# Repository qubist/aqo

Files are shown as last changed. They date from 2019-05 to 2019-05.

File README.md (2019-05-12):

# aqo

Banner image of aqo next to a monitor and keyboard



> Air Quality Object which beautifully and passively displays the level of CO2 in the air

## Table of Contents

- [Background](#background)
- [Install/Assembly](#installassembly)
- [Parts](#parts)
- [Usage](#usage)
- [Maintainers](#maintainers)
- [Contributing](#contributing)
- [License](#license)

## Background

[Too much CO2 in the air affects how well brains function.](https://ehp.niehs.nih.gov/doi/pdf/10.1289/ehp.1510037#page=6&zoom=auto,-131,530) The Air Quality Object changes color depending on air CO2 content. It's meant to be a beautiful object which also passively displays information about the surroundings. It makes a normally invisible flow visible, so you can open a window when your air is getting stale.

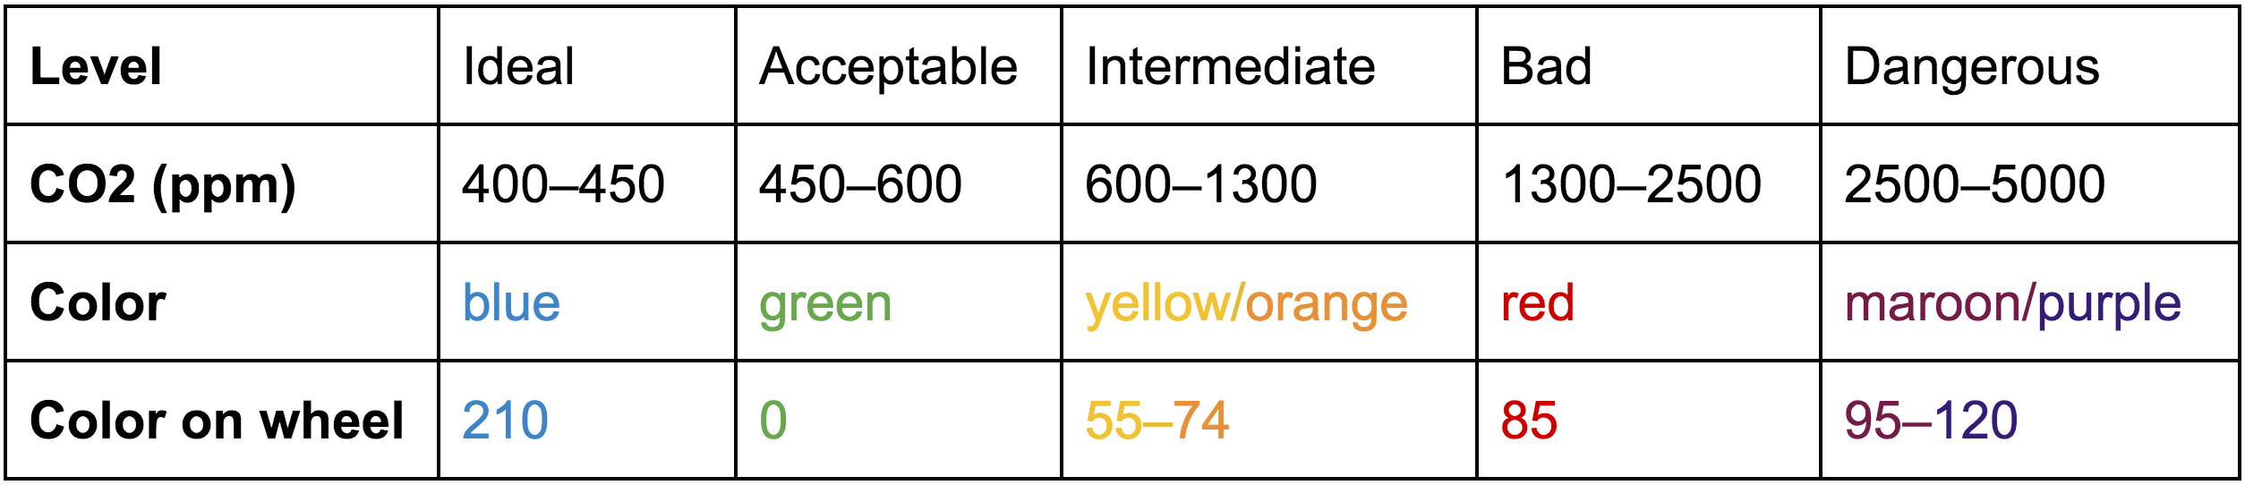
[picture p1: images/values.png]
Chart displaying 5 levels of air quality. Each level has three data points: CO2 (ppm), Color, and Color on wheel. Ideal: 400–450 ppm, blue, 210; Acceptable: 450–600 ppm, green, 0; Intermediate: 600–1300 ppm, yellow/orange, 55–74; Bad: 1300–2500, red, 85; Dangerous: 2500–5000, maroon/purple, 95–120


aqo alongside parts required to build it

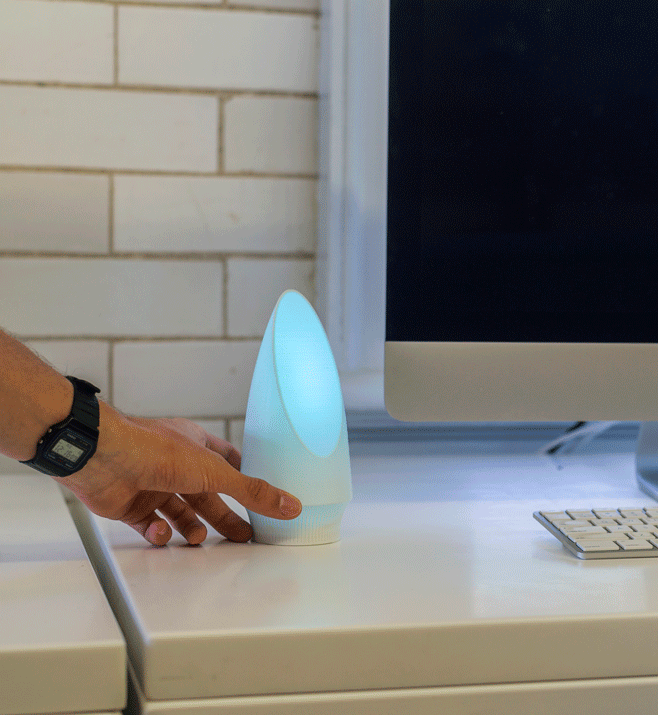
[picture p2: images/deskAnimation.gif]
Gif showing an aqo displaying various colors being touched by a hand wearing a watch


## Install/Assembly

Install the code on an [Adafruit Feather M0 Express](https://www.adafruit.com/product/3403) by dragging the contents of the [code](/code) folder (`lib`, `main.py` and `helpers.py`) onto the Feather's CIRCUITPY drive.

aqo next to a laptop showing code

### Parts
* [Adafruit SGP30 Air Quality Sensor Breakout](https://www.adafruit.com/product/3709) for measuring CO2
* [Adafruit NeoPixel Stick 8x RGB LED](https://www.adafruit.com/product/1426) for displaying the color
* [3.7v 1200mAh LiPo Battery](https://www.adafruit.com/product/258) for backup power
* [Adafruit Feather M0 Express](https://www.adafruit.com/product/3403) to control everything

Parts that are used to create aqo

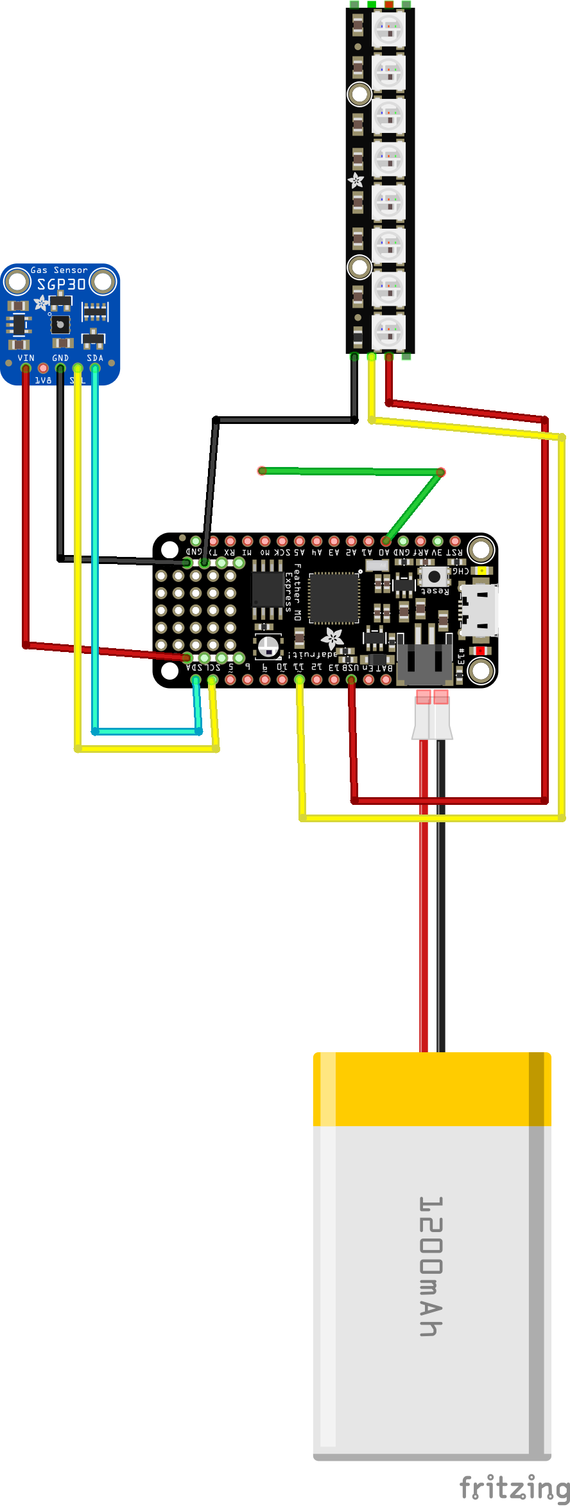
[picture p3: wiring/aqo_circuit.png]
Circuit diagram for the aqo, showing how to connect the Feather M0, SPG30, NeoPixel Bar, and battery together


## Usage

The aqo will start displaying the color based on what CO2 readings it's getting. At first, this won't be accurate. Bring it outside for like 10 minutes so that the sensor can get a baseline reading of clean air. Then after a while it should display the colors accurately to the CO2 levels in the air.*

Touch the touchwire on the back of the aqo to change which brightness mode you're in. The brightest one is good for daytime, middle is good for nighttime, and lowest is good for sleeping.

The aqo should stay plugged in, but it has a battery and can be unplugged for periods of time. This is useful so you can transport it or take it outside without it rebooting and losing its calibration.

To remove the bottom cover for maintenance, twist it and the magnets will disengage. Then it should pop free. You can also lever it free using the power cable or maybe even shake it free.

\* I'm not 100% sure about all this stuff. I'll try and figure it out later.

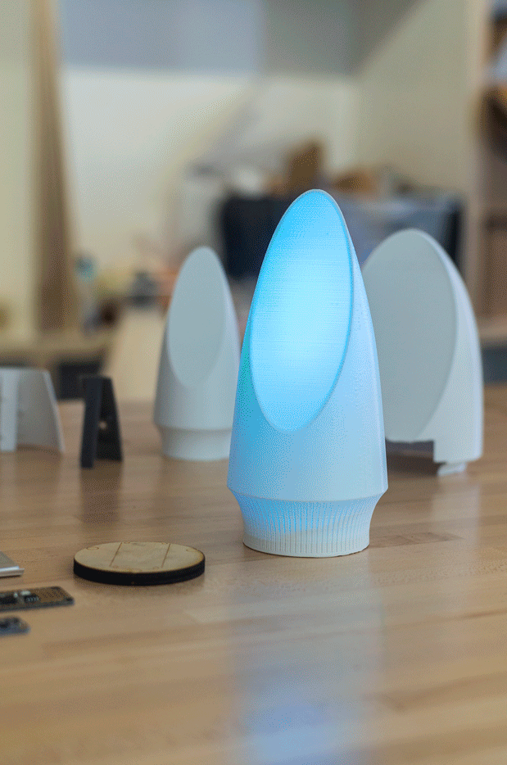
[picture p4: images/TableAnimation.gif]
Gif showing an aqo displaying various colors sitting on a table


## Maintainers

[@qubist](https://github.com/qubist)

## Contributing

PRs accepted.

Note: If editing the README, please conform to the [standard-readme](https://github.com/RichardLitt/standard-readme) specification.

## License

MIT © 2019 Will

Banner image of aqo showing orange next to a Prusa i3 Mk2 3D printer

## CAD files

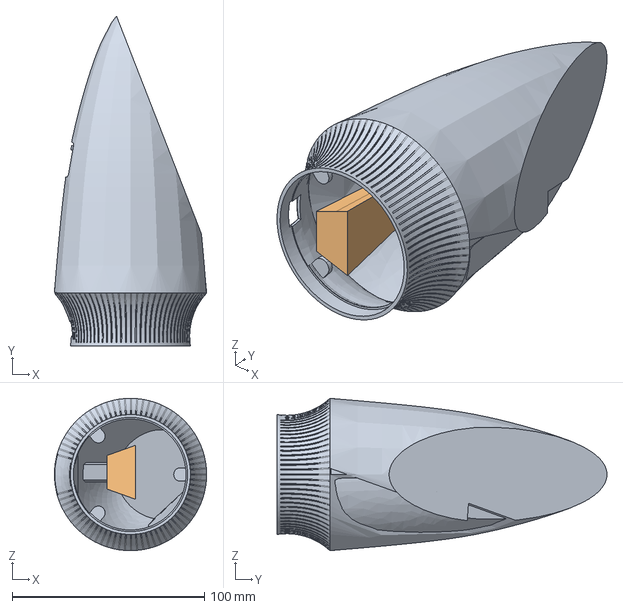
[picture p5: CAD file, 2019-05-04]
case/Case.igs
79.2 x 171.7 x 79.2 mm

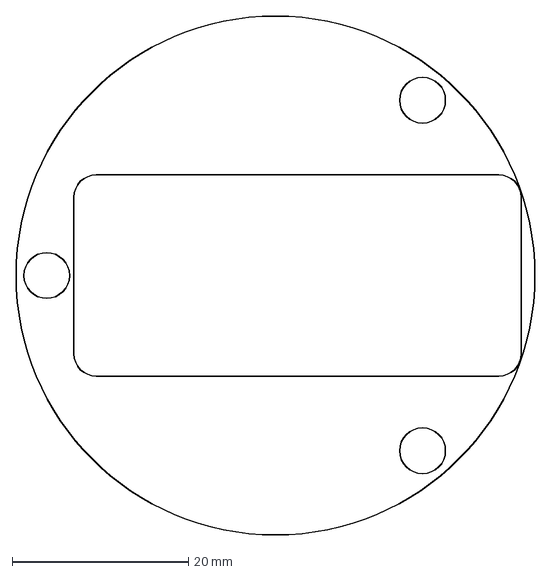
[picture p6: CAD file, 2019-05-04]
case/aqo_bottom_cover_v124.dxf
58.9 x 58.9 mm

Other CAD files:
case/Case.f3z

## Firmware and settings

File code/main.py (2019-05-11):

import time
import board
import busio
import adafruit_sgp30
import neopixel
import touchio
from analogio import AnalogIn

from helpers import *

PIXEL_PIN = board.D11
NUM_PIXELS = 8

# pin with touch sensitivity
TOUCH_PIN = board.A0

# pin with battery voltage for checking battery level
VBATPIN = board.D9

DISPLAY_BRIGHTNESS = 1

# number of entries to average to get the displayed value
# the higher this is, the slower and smoother color transitions will be
# 60-80 seems to be good for nice slow transitions while staying responsive
BLUR_AMOUNT = 25

# LOWBAT_PULSE_SPEED = 200
# LOWBAT_PULSE_DEPTH = 200

# voltages at which low battery mode is turned off or on when battery voltage is
# ascending or descending
# VBAT_DESCENT_THRESHOLD = 3.35
# VBAT_ASCENT_THRESHOLD = 3.45

# in each mode, how much to dim the pixels and how many of the pixels to light
DEFAULT_DIM_FACTOR = 1 # don't dim in mode 0
DEFAULT_DIM_MAPPING = [1,1,1,1,1,1,1,1]

FIRST_DIM_FACTOR  = 1 # don't dim
FIRST_DIM_MAPPING = [0,1,0,0,1,0,0,1]

SECOND_DIM_FACTOR = 20 # dim a lot mode 2
SECOND_DIM_MAPPING = [1,0,0,0,0,0,0,0]

UBER_DIM_FACTOR = 30

# set up pixel array
pixels = neopixel.NeoPixel(PIXEL_PIN, NUM_PIXELS, brightness=DISPLAY_BRIGHTNESS, auto_write=True)

# set up touch sensitivity
touch_pad = TOUCH_PIN
touch = touchio.TouchIn(touch_pad)

# VBatAnalogIn = AnalogIn(VBATPIN)
# def getBatteryVoltage():
#     return getVoltage(VBatAnalogIn) * 2

# Turn off board neopixel
boardPixel = neopixel.NeoPixel(board.NEOPIXEL, 1, auto_write=True)
boardPixel[0] = 0

# Set up I2C for CO2 sensor
i2c = busio.I2C(board.SCL, board.SDA, frequency=100000)
# Create library object on our I2C port
sgp30 = adafruit_sgp30.Adafruit_SGP30(i2c)
print("SGP30 serial #", [hex(i) for i in sgp30.serial])
sgp30.iaq_init()
sgp30.set_iaq_baseline(0x8973, 0x8aae)

# define an average function that calculates the average of our values
def avg(lst):
    return sum(lst)/BLUR_AMOUNT

# returns a value on the color wheel described in the wheel() function
# based a given CO2 level
def getWheelValueFromCO2(CO2):
    if inRange(CO2, 400,450):
        return mapFromTo(CO2, 400,450, 210,255)
    elif inRange(CO2, 450,600):
        return mapFromTo(CO2, 450,600, 0,55)
    elif inRange(CO2, 600,1300):
        return mapFromTo(CO2, 600,1300, 55,85)
    elif inRange(CO2, 1300,2500):
        return mapFromTo(CO2, 1300,2500, 85,95)
    elif inRange(CO2, 2500,5000):
        return mapFromTo(CO2, 2500,5000, 95,120)
    else:
        return 120

# returns a color
def getColorFromCO2(CO2):
    return wheel(getWheelValueFromCO2(CO2))

# shows the color, lighting the pixels corresponding to 1s in a binary array
def showColor(color, mapping=[1,1,1,1,1,1,1,1]):
    # if in UberDIM mode, turn off all pixels but light the board pixel
    if(mapping == "uberdim"):
        pixels.fill(0)
        boardPixel[0] = color
    else:
        # turn off the board pixel
        boardPixel[0] = 0
        # crawl the mapping and light up the pixels which should be activated
        for n,m in enumerate(mapping):
            if m == 1:
                pixels[n] = color
            else:
                pixels[n] = 0

# runs a startup animation
# lights turn on from bottom to top, with a slight color change.
def startupAnimation(delay, destinationColor, colorStep):
    # start out with all pixels off
    animationMapping = [0,0,0,0,0,0,0,0]
    i = 0
    # start the color the right amount away from destination
    color = destinationColor + colorStep * 8
    for i in range(8):
        animationMapping[i] = 1
        showColor(wheel(color), animationMapping)
        color -= colorStep
        time.sleep(delay)

# set up list of last values to update and average
vals = [400 for x in range(BLUR_AMOUNT)]
# batLow = False
tick = int(time.monotonic())

touched = False
mode = 0

# show startup animation
startupAnimation(.045, 210, 3)

while True:
    # update which second are we on, and save the last one
    lastTick = [tick][0]
    tick = int(time.monotonic())

    # check touches and cycle through brightness modes if new touch is detected
    if touch.value:
        if touched == False:
            # activate touch functions
            # print("TOUCHED!")
            # increment mode
            mode = increment(mode)

            touched = True
    else:
        touched = False

    # grab the carbon dioxide and TVOC levels from the sensor
    # eCO2, TVOC = sgp30.eCO2, sgp30.TVOC
    eCO2 = sgp30.eCO2

    # only do the following every 10 seconds (on rising edge of 10th second)
    # if tick % 10 == 0 and lastTick %10 != 0:
    #     # get the battery voltage
    #     voltage = getBatteryVoltage()
    #     print(voltage)
    #     if batLow == False and voltage <= VBAT_DESCENT_THRESHOLD:
    #         batLow = True
    #     elif batLow == True and voltage >= VBAT_ASCENT_THRESHOLD:
    #         batLow = False

    # remove oldest datapoint from our list of values and add the new datapoint
    vals.remove(vals[0])
    vals.append(eCO2)

    # the value we'll work with is the average of our list of values
    blurredVal = avg(vals)

    # these print statements are usefull, but slow down the program if it's not
    # plugged in and able to actually print to serial
    # print(vals)
    # print("eCO2 = %d ppm" % (sgp30.eCO2))
    # print(blurredVal)
    # print(voltage)

    c = getColorFromCO2(blurredVal)
    if mode == 0:
        displayColor = c # don't dim
        pixelMapping = DEFAULT_DIM_MAPPING
    elif mode == 1:
        displayColor = dim(c, FIRST_DIM_FACTOR)
        pixelMapping = FIRST_DIM_MAPPING
    elif mode == 2:
        displayColor = dim(c, SECOND_DIM_FACTOR) # SuperDim for nighttime :)
        pixelMapping = SECOND_DIM_MAPPING
    elif mode == 3:
        displayColor = dim(c, UBER_DIM_FACTOR) # UberDIM !! >:}
        pixelMapping = "uberdim"

    # # pulse the display color if in low battery mode
    # if batLow == True:
    #     ShowColor(pulse(displayColor, LOWBAT_PULSE_SPEED, LOWBAT_PULSE_DEPTH), pixelMapping)
    # # otherwise just display the color
    # else:
    showColor(displayColor, pixelMapping)

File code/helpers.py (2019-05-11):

import time

MAX_MODE = 3

def wheel(pos):
    # Input a value 0 to 255 to get a color value.
    # The colours are a transition r - g - b - back to r.
    if pos < 0 or pos > 255:
        r = g = b = 0
    elif pos < 85:
        r = int(pos * 3)
        g = int(255 - pos*3)
        b = 0
    elif pos < 170:
        pos -= 85
        r = int(255 - pos*3)
        g = 0
        b = int(pos*3)
    else:
        pos -= 170
        r = 0
        g = int(pos*3)
        b = int(255 - pos*3)
    return (r, g, b)

# x    input value;
# a,b  input range
# c,d  output range
# y    return value
def mapFromTo(x,a,b,c,d):
   y=(x-a)/(b-a)*(d-c)+c
   return y

# returns bool: whether n is in the given range
# lower inclusive, upper exclusive (min <= n < max)
def inRange(n, min, max):
    return n < max and n >= min

def dim(color, factor):
    r, g, b = color
    dimmedColor = int(r/factor), int(g/factor), int(b/factor)
    return dimmedColor

def getVoltage(pin):
    return (pin.value * 3.3) / 65536

# pulses the input color's brightness according to the device time
# speed: the speed at which the pulse pulses. 100 is medium, 300 is very slow.
# depth: how dim the pulse gets at its dimmest. higher values are less
#        dim. 10 is medium, 2 is very deep, 30 is very shallow.
def pulse(color, speed, depth):
    milliseconds = int(time.monotonic()*100)
    # print("time:",time.monotonic())
    timeValue = abs(milliseconds % speed - speed//2)
    # print(timeValue)
    dimAmount = timeValue/depth + 1
    # print(dimAmount)
    return dim(color, dimAmount)

def increment(mode):
    if mode == MAX_MODE:
        return 0
    else:
        return mode + 1

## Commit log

2019-02-07 Add voltage calculator helper function
2019-02-07 Add battery voltage checking and longer CO2 sample
2019-02-07 Parameterize thresholds for low battery indication
2019-02-08 Fix every 10 second battery checking
    [main.py]
2019-02-15 Switch around order of functions
2019-02-15 Update to color calculation
    Colors now cycle blue -> green -> orange -> red -> purple. Also with the
    correct ratios according to plans
    [main.py]
2019-05-04 Redo dimming so that brightness and amount of LEDs activated can be set
2019-05-04 Adjust battery and blur values
2019-05-04 Add case and wiring files
    [Case.f3z, Case.igs, aqo_bottom_cover_v124.dxf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]
2019-05-06 Remove low battery functionality
2019-05-11 Add new dimness mode which activates the board LED
